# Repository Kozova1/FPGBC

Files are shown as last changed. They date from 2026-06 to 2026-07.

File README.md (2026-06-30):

# FPGBC - Field Programmable Game Boy Cartridge
This is a project for an open-source cartridge for the Game Boy (Color).
Each cartridge contains an iCE40UP5K FPGA, interfacing through level shifters with the Game Boy and through an MCP2210 with your PC.
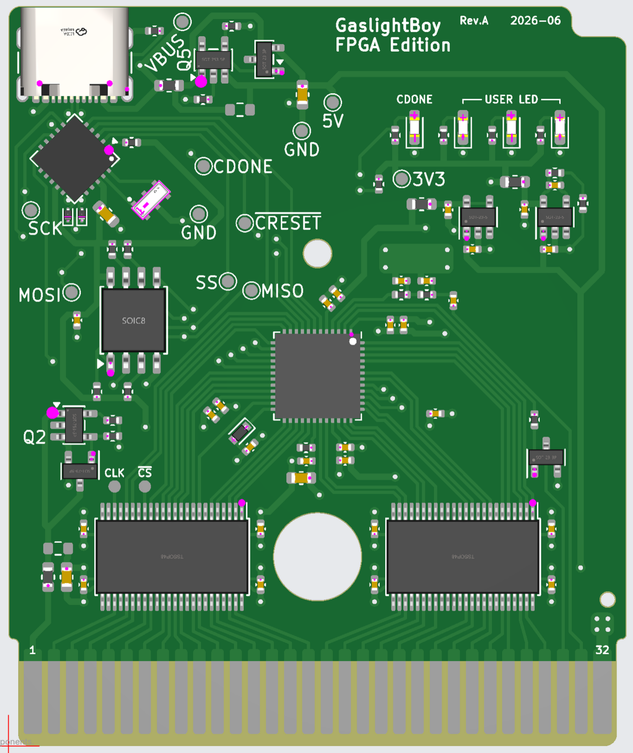
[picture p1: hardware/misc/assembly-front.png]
Field Programmable Game Boy Cartridge


## Licensing
The hardware is licensed under the [BSD 3-clause license](./hardware/LICENSE),
being a modified version of [tsuraraGB](https://github.com/rniwase/tsuraraGB/).

All non-hardware code (including FPGA code, python tooling, etc.) is licensed under the [GPLv3](./LICENSE)

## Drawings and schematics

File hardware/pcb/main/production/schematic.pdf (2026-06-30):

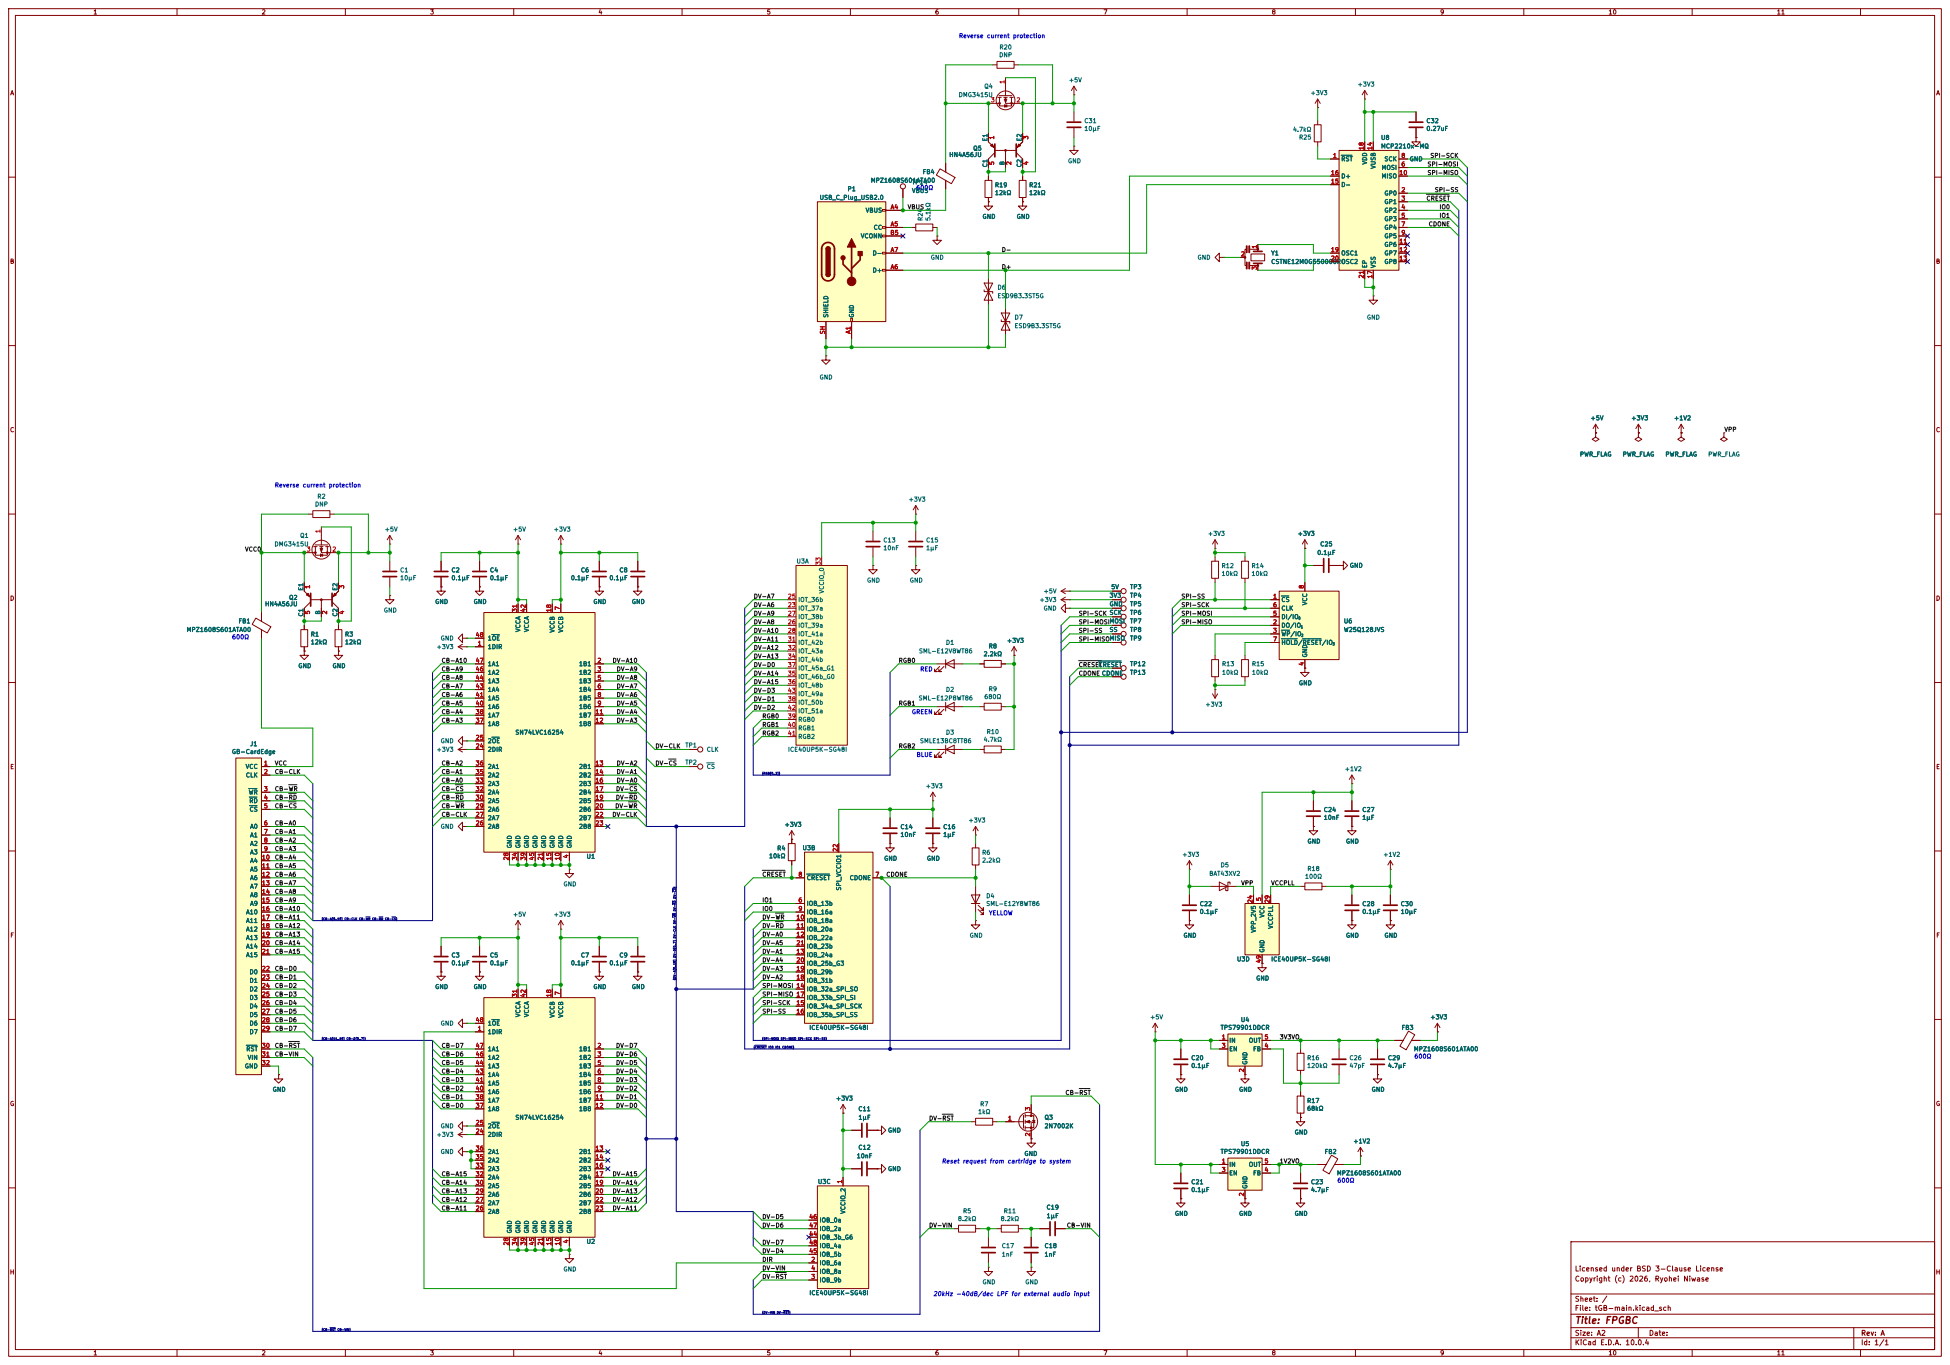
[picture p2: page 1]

GND | D+

BLUE Reverse current protection 600Ω

SPI-SS
SPI-MOSI SPI-SCK

SPI-MOSI SPI-SS CB-RD

{CB-A[0..10] CB-CLK CB-WR CB-RD CB-CS} CB-A12 CB-A10 CB-RST CB-VIN

{SPI-MOSI SPI-MISO SPI-SCK SPI-SS} DV-A0

Reset request from cartridge to system

{DV-VIN DV-RST} DV-VIN

Licensed under BSD 3-Clause License
Copyright (c) 2026, Ryohei Niwase

20kHz -40dB/dec LPF for external audio input

Size: A2 | Rev: A
KiCad E.D.A. 10.0.4 | Id: 1/1

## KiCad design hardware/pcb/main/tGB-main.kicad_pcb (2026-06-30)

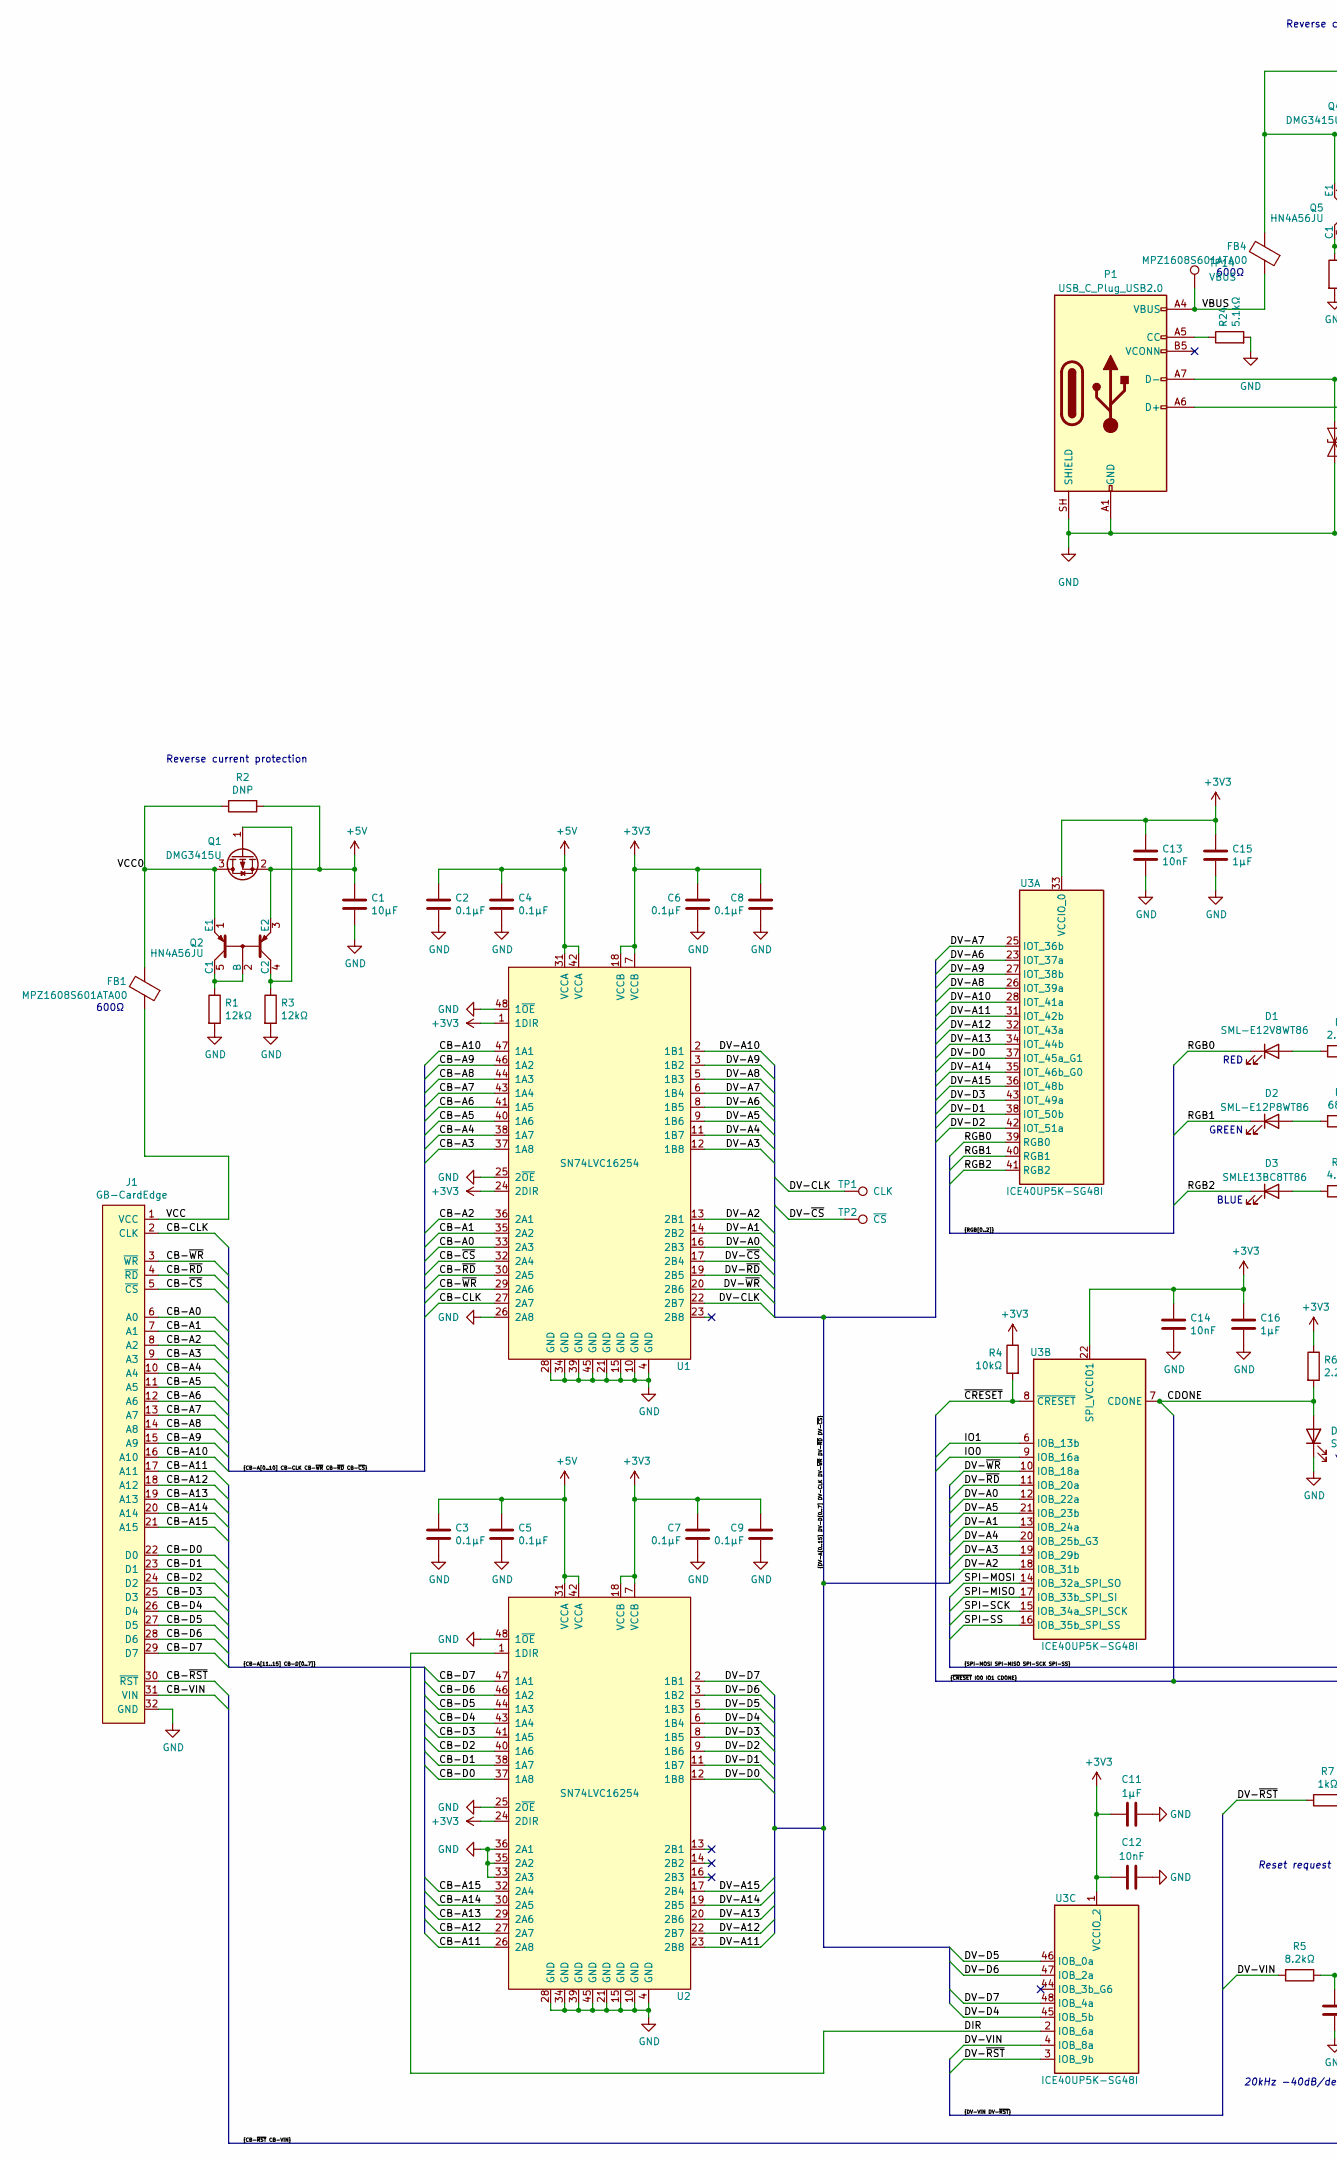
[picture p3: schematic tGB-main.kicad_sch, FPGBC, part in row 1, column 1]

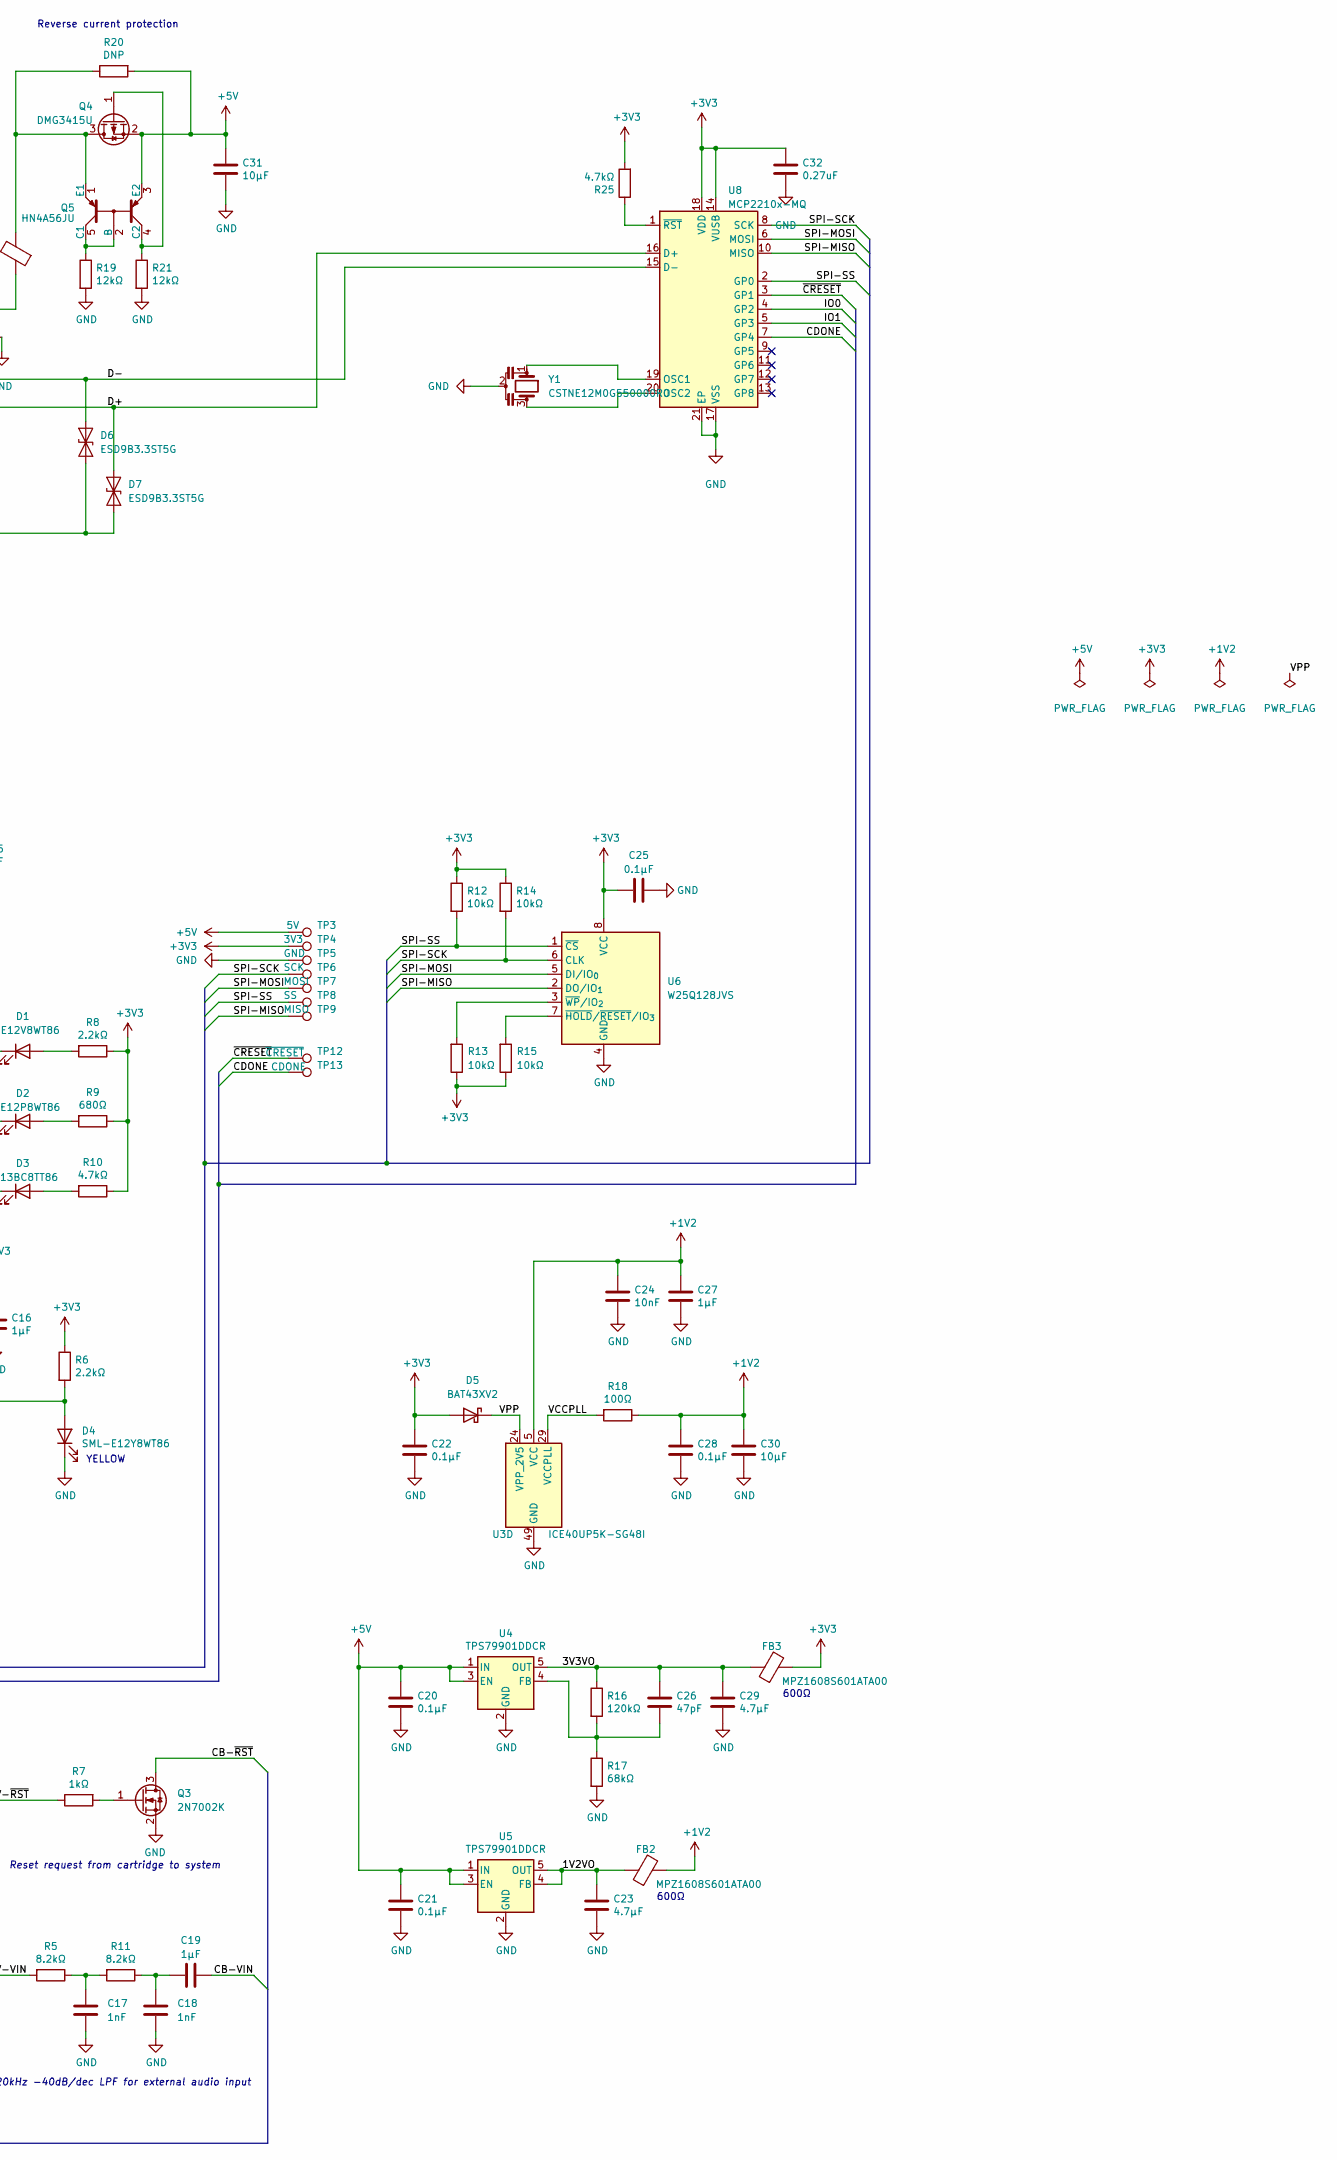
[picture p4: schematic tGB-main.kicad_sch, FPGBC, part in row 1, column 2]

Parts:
C1, C30, C31: 10μF; C_0603_1608Metric
C2, C3, C4, C5, C6, C7, C8, C9, C20, C21, C22, C25, C28: 0.1μF; C_0402_1005Metric
C11, C15, C16, C19, C27: 1μF; C_0402_1005Metric
C12, C13, C14, C24: 10nF; C_0402_1005Metric
C17, C18: 1nF; C_0402_1005Metric
C23, C29: 4.7μF; C_0402_1005Metric
C26: 47pF; C_0402_1005Metric
C32: 0.27uF; C_0603_1608Metric
D1: SML-E12V8WT86; LED_0603_1608Metric_Castellated
D2: SML-E12P8WT86; LED_0603_1608Metric_Castellated
D3: SMLE13BC8TT86; LED_0603_1608Metric_Castellated
D4: SML-E12Y8WT86; LED_0603_1608Metric_Castellated
D5: BAT43XV2; D_SOD-523
D6, D7: ESD9B3.3ST5G; D_SOD-923
FB1, FB2, FB3, FB4: MPZ1608S601ATA00; L_0603_1608Metric
J1: GB-CardEdge
P1: USB_C_Plug_USB2.0; USB_C_Receptacle_GCT_USB4105-xx-A_16P_TopMnt_Horizontal
Q1, Q4: DMG3415U; SOT-23
Q2, Q5: HN4A56JU; SC-74A-5_1.55x2.9mm_P0.95mm
Q3: 2N7002K; SOT-23
R1, R3, R19, R21: 12kΩ; R_0402_1005Metric
R2, R20: DNP; R_0603_1608Metric
R4, R12, R13, R14, R15: 10kΩ; R_0402_1005Metric
R5, R11: 8.2kΩ; R_0402_1005Metric
R6, R8: 2.2kΩ; R_0402_1005Metric
R7: 1kΩ; R_0402_1005Metric
R9: 680Ω; R_0402_1005Metric
R10, R25: 4.7kΩ; R_0402_1005Metric
R16: 120kΩ; R_0402_1005Metric
R17: 68kΩ; R_0402_1005Metric
R18: 100Ω; R_0402_1005Metric
R24: 5.1kΩ; R_0402_1005Metric
TP1: CLK; TestPoint_Pad_D1.0mm
TP2: ~{CS}; TestPoint_Pad_D1.0mm
TP3: 5V; TestPoint_Pad_D1.0mm
TP4: 3V3; TestPoint_Pad_D1.0mm
TP5: GND; TestPoint_Pad_D1.0mm
TP6: SCK; TestPoint_Pad_D1.0mm
TP7: MOSI; TestPoint_Pad_D1.0mm
TP8: SS; TestPoint_Pad_D1.0mm
TP9: MISO; TestPoint_Pad_D1.0mm
TP12: ~{CRESET}; TestPoint_Pad_D1.0mm
TP13: CDONE; TestPoint_Pad_D1.0mm
TP14: VBUS; TestPoint_Pad_D1.0mm
U1, U2: SN74LVC16254; TSSOP-48_6.1x12.5mm_P0.5mm
U3: ICE40UP5K-SG48I; QFN-48-1EP_7x7mm_P0.5mm_EP5.6x5.6mm
U4, U5: TPS79901DDCR; SOT-23-5
U6: W25Q128JVS; SOIC-8_5.3x5.3mm_P1.27mm
U8: MCP2210x-MQ; QFN-20-1EP_5x5mm_P0.65mm_EP3.35x3.35mm
Y1: CSTNE12M0G550000R0; CSTNE10M0G55A000R0

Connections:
+1V2: C24.1, C27.1, C28.1, C30.1, FB2.2, R18.1, U3.5 (VCC), U3.30 (VCC)
+3V3: C6.1, C7.1, C8.1, C9.1, C11.1, C12.1, C13.1, C14.1, C15.1, C16.1, C22.1, C25.1, C32.1, D5.2 (A), FB3.2, R4.1, R6.1, R8.1, R9.1, R10.1, R12.1, R13.1, R14.1, R15.1, R25.2, TP4.1 (1_1), U1.1 (1DIR), U1.7 (VCCB), U1.18 (VCCB), U1.24 (2DIR), U2.7 (VCCB), U2.18 (VCCB), U2.24 (2DIR), U3.1 (VCCIO_2), U3.22 (SPI_VCCIO1), U3.33 (VCCIO_0), U6.8 (VCC), U8.14 (VUSB), U8.18 (VDD); also elsewhere on the board
+5V: C1.1, C2.1, C3.1, C4.1, C5.1, C20.1, C21.1, C31.1, Q1.2 (S), Q2.3 (E2), Q4.2 (S), Q5.3 (E2), R2.2, R20.2, TP3.1 (1_1), U1.31 (VCCA), U1.42 (VCCA), U2.31 (VCCA), U2.42 (VCCA), U4.1 (IN), U4.3 (EN), U5.1 (IN), U5.3 (EN)
/1V2VO: C23.1, FB2.1, U5.4 (FB), U5.5 (OUT)
/3V3VO: C26.1, C29.1, FB3.1, R16.1, U4.5 (OUT)
/CB-A0: J1.6 (A0), U1.33 (2A3)
/CB-A1: J1.7 (A1), U1.35 (2A2)
/CB-A2: J1.8 (A2), U1.36 (2A1)
/CB-A3: J1.9 (A3), U1.37 (1A8)
/CB-A4: J1.10 (A4), U1.38 (1A7)
/CB-A5: J1.11 (A5), U1.40 (1A6)
/CB-A6: J1.12 (A6), U1.41 (1A5)
/CB-A7: J1.13 (A7), U1.43 (1A4)
/CB-A8: J1.14 (A8), U1.44 (1A3)
/CB-A9: J1.15 (A9), U1.46 (1A2)
/CB-A10: J1.16 (A10), U1.47 (1A1)
/CB-A11: J1.17 (A11), U2.26 (2A8)
/CB-A12: J1.18 (A12), U2.27 (2A7)
/CB-A13: J1.19 (A13), U2.29 (2A6)
/CB-A14: J1.20 (A14), U2.30 (2A5)
/CB-A15: J1.21 (A15), U2.32 (2A4)
/CB-CLK: J1.2 (CLK), U1.27 (2A7)
/CB-D0: J1.22 (D0), U2.37 (1A8)
/CB-D1: J1.23 (D1), U2.38 (1A7)
/CB-D2: J1.24 (D2), U2.40 (1A6)
/CB-D3: J1.25 (D3), U2.41 (1A5)
/CB-D4: J1.26 (D4), U2.43 (1A4)
/CB-D5: J1.27 (D5), U2.44 (1A3)
/CB-D6: J1.28 (D6), U2.46 (1A2)
/CB-D7: J1.29 (D7), U2.47 (1A1)
/CB-VIN: C19.1, J1.31 (VIN)
/CB-~CS: J1.5 (~CS), U1.32 (2A4)
/CB-~RD: J1.4 (~RD), U1.30 (2A5)
/CB-~RST: J1.30 (~RST), Q3.3 (D)
/CB-~WR: J1.3 (~WR), U1.29 (2A6)
/CDONE: D4.2 (A), R6.2, TP13.1 (1_1), U3.7 (CDONE), U8.7 (GP4)
/D+: D7.2 (A2), P1.A6 (D+), U8.16 (D+)
/D-: D6.2 (A2), P1.A7 (D-), U8.15 (D-)
/DIR: U2.1 (1DIR), U3.2 (IOB_6a)
/DV-A0: U1.16 (2B3), U3.12 (IOB_22a)
/DV-A1: U1.14 (2B2), U3.13 (IOB_24a)
/DV-A2: U1.13 (2B1), U3.18 (IOB_31b)
/DV-A3: U1.12 (1B8), U3.19 (IOB_29b)
/DV-A4: U1.11 (1B7), U3.20 (IOB_25b_G3)
/DV-A5: U1.9 (1B6), U3.21 (IOB_23b)
/DV-A6: U1.8 (1B5), U3.23 (IOT_37a)
/DV-A7: U1.6 (1B4), U3.25 (IOT_36b)
/DV-A8: U1.5 (1B3), U3.26 (IOT_39a)
/DV-A9: U1.3 (1B2), U3.27 (IOT_38b)
/DV-A10: U1.2 (1B1), U3.28 (IOT_41a)
/DV-A11: U2.23 (2B8), U3.31 (IOT_42b)
/DV-A12: U2.22 (2B7), U3.32 (IOT_43a)
/DV-A13: U2.20 (2B6), U3.34 (IOT_44b)
/DV-A14: U2.19 (2B5), U3.35 (IOT_46b_G0)
/DV-A15: U2.17 (2B4), U3.36 (IOT_48b)
/DV-CLK: TP1.1 (1_1), U1.22 (2B7)
/DV-D0: U2.12 (1B8), U3.37 (IOT_45a_G1)
/DV-D1: U2.11 (1B7), U3.38 (IOT_50b)
/DV-D2: U2.9 (1B6), U3.42 (IOT_51a)
/DV-D3: U2.8 (1B5), U3.43 (IOT_49a)
/DV-D4: U2.6 (1B4), U3.45 (IOB_5b)
/DV-D5: U2.5 (1B3), U3.46 (IOB_0a)
/DV-D6: U2.3 (1B2), U3.47 (IOB_2a)
/DV-D7: U2.2 (1B1), U3.48 (IOB_4a)
/DV-VIN: R5.2, U3.4 (IOB_8a)
/DV-~CS: TP2.1 (1_1), U1.17 (2B4)
/DV-~RD: U1.19 (2B5), U3.11 (IOB_20a)
/DV-~RST: R7.1, U3.3 (IOB_9b)
/DV-~WR: U1.20 (2B6), U3.10 (IOB_18a)
/IO0: U3.9 (IOB_16a), U8.4 (GP2)
/IO1: U3.6 (IOB_13b), U8.5 (GP3)
/RGB0: D1.1 (K), U3.39 (RGB0)
/RGB1: D2.1 (K), U3.40 (RGB1)
/RGB2: D3.1 (K), U3.41 (RGB2)
/SPI-MISO: TP9.1 (1_1), U3.17 (IOB_33b_SPI_SI), U6.2 (DO/IO_{1}), U8.10 (MISO)
/SPI-MOSI: TP7.1 (1_1), U3.14 (IOB_32a_SPI_SO), U6.5 (DI/IO_{0}), U8.6 (MOSI)
/SPI-SCK: R14.2, TP6.1 (1_1), U3.15 (IOB_34a_SPI_SCK), U6.6 (CLK), U8.8 (SCK)
/SPI-SS: R12.2, TP8.1 (1_1), U3.16 (IOB_35b_SPI_SS), U6.1 (~CS), U8.2 (GP0)
/VBUS: FB4.1, P1.A4 (VBUS), P1.A9 (VBUS), P1.B4 (VBUS), P1.B9 (VBUS), TP14.1 (1_1)
/VCC: FB1.1, J1.1 (VCC)
/VCC0: FB1.2, Q1.3 (D), Q2.1 (E1), R2.1
/VCCPLL: R18.2, U3.29 (VCCPLL)
/VPP: D5.1 (K), U3.24 (VPP_2V5)
/~CRESET: R4.2, TP12.1 (1_1), U3.8 (~CRESET), U8.3 (GP1)
GND: C1.2, C2.2, C3.2, C4.2, C5.2, C6.2, C7.2, C8.2, C9.2, C11.2, C12.2, C13.2, C14.2, C15.2, C16.2, C17.2, C18.2, C20.2, C21.2, C22.2, C23.2, C24.2, C25.2, C27.2, C28.2, C29.2, C30.2, C31.2, C32.2, D4.1 (K), D6.1 (A1), D7.1 (A1), J1.32 (GND), P1.A1 (GND), P1.A12 (GND), P1.B1 (GND), P1.B12 (GND), P1.SH (SHIELD), Q3.2 (S), R1.2, R3.2, R17.2, R19.2, R21.2, R24.2, TP5.1 (1_1), U1.4 (GND), U1.10 (GND), U1.15 (GND), U1.21 (GND), U1.25 (2~OE), U1.26 (2A8), U1.28 (GND), U1.34 (GND), U1.39 (GND), U1.45 (GND), U1.48 (1~OE), U2.4 (GND), U2.10 (GND), U2.15 (GND), U2.21 (GND), U2.25 (2~OE), U2.28 (GND), U2.33 (2A3), U2.34 (GND), U2.35 (2A2), U2.36 (2A1), U2.39 (GND), U2.45 (GND), U2.48 (1~OE), U3.49 (GND), U4.2 (GND), U5.2 (GND), U6.4 (GND), U8.17 (VSS), U8.21 (EP), Y1.2; also elsewhere on the board
unnamed: C17.1, R5.1, R11.2
unnamed: C18.1, C19.2, R11.1
unnamed: D1.2 (A), R8.2
unnamed: D2.2 (A), R9.2
unnamed: D3.2 (A), R10.2
unnamed: P1.A5 (CC), R24.1
unnamed: Q1.1 (G), Q2.4 (C2), R3.1
unnamed: Q2.2 (B), Q2.5 (C1), R1.1
unnamed: Q3.1 (G), R7.2
unnamed: FB4.2, Q4.3 (D), Q5.1 (E1), R20.1
unnamed: Q4.1 (G), Q5.4 (C2), R21.1
unnamed: Q5.2 (B), Q5.5 (C1), R19.1
unnamed: C26.2, R16.2, R17.1, U4.4 (FB)
unnamed: R15.2, U6.7 (~HOLD/~RESET/IO_{3})
unnamed: R13.2, U6.3 (~WP/IO_{2})
unnamed: U8.19 (OSC1), Y1.1
unnamed: U8.20 (OSC2), Y1.3
unnamed: R25.1, U8.1 (~RST)

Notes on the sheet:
Reverse current protection
GREEN
600Ω
YELLOW
RED
Reset request from cartridge to system
BLUE
20kHz -40dB/dec LPF for external audio input

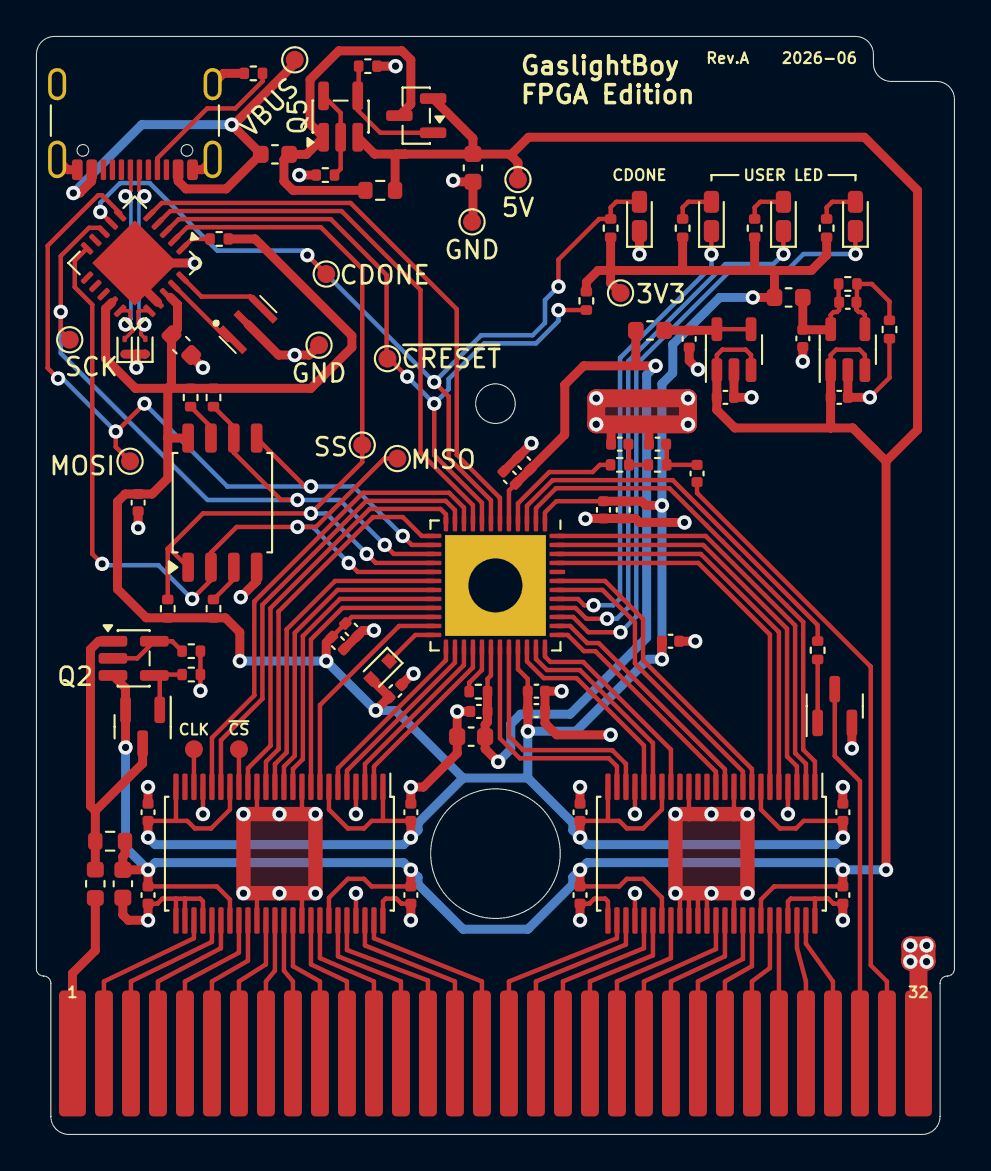
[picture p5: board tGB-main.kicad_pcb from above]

Board: 2 copper layers, 51.0 x 61.0 mm, 94 parts (0 on the bottom side), 103 nets.

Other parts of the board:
C10: 0.1μF; C_0402_1005Metric
TP10: GND; TestPoint_Pad_D1.0mm

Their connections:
+3V3: C10.1; also elsewhere on the board
GND: C10.2, TP10.1 (1_1); also elsewhere on the board

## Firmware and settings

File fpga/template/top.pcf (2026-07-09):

set_io DATA[7] 48
set_frequency DATA[7] 4

set_io DATA[6] 47
set_frequency DATA[6] 4

set_io DATA[5] 46
set_frequency DATA[5] 4

set_io DATA[4] 45
set_frequency DATA[4] 4

set_io DATA[3] 43
set_frequency DATA[3] 4

set_io DATA[2] 42
set_frequency DATA[2] 4

set_io DATA[1] 38
set_frequency DATA[1] 4

set_io DATA[0] 37
set_frequency DATA[0] 4

set_io ADDRESS[15] 36
set_frequency ADDRESS[15] 4

set_io ADDRESS[14] 35
set_frequency ADDRESS[14] 4

set_io ADDRESS[13] 34
set_frequency ADDRESS[13] 4

set_io ADDRESS[12] 32
set_frequency ADDRESS[12] 4

set_io ADDRESS[11] 31
set_frequency ADDRESS[11] 4

set_io ADDRESS[10] 28
set_frequency ADDRESS[10] 4

set_io ADDRESS[9] 27
set_frequency ADDRESS[9] 4

set_io ADDRESS[8] 26
set_frequency ADDRESS[8] 4

set_io ADDRESS[7] 25
set_frequency ADDRESS[7] 4

set_io ADDRESS[6] 23
set_frequency ADDRESS[6] 4

set_io ADDRESS[5] 21
set_frequency ADDRESS[5] 4

set_io ADDRESS[4] 20
set_frequency ADDRESS[4] 4

set_io ADDRESS[3] 19
set_frequency ADDRESS[3] 4

set_io ADDRESS[2] 18
set_frequency ADDRESS[2] 4

set_io ADDRESS[1] 13
set_frequency ADDRESS[1] 4

set_io ADDRESS[0] 12
set_frequency ADDRESS[0] 4

set_io nRD 11
set_frequency nRD 4

set_io nWR 10
set_frequency nWR 4

set_io nRST 3
set_frequency nRST 4

set_io VIN 4
set_frequency VIN 4

set_io DIR_DATA 2
set_frequency DIR_DATA 4

set_io SPI_SCK 15
set_frequency SPI_SCK 4

set_io SPI_MOSI 14
set_frequency SPI_MOSI 4

set_io SPI_MISO 17
set_frequency SPI_MISO 4

set_io SPI_SS 16
set_frequency SPI_SS 4

set_io IO[1] 6
set_frequency IO[1] 4

set_io IO[0] 9
set_frequency IO[0] 4

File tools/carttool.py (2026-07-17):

import argparse
from itertools import batched
import math
from pathlib import Path
import time

import hid
import mcp2210

from loguru import logger
from mcp2210.mcp2210 import Mcp2210GpioDirection, Mcp2210GpioDesignation
from tqdm import tqdm, trange

from tools.spi_flash import W25Q128JVS

from .types import hex_integer
from .argparse_tree import Argument, LeafCommand, Command, make_parser

PROGRAM_NAME = "carttool.py"

USB_VID = 0x04D8
USB_PID = 0xE429

MCP2210_IO_CONFIG_COMMAND = bytes.fromhex(
    "60 20 00 00 " # Set Chip NVRAM Power-up Default
    "01 00 00 00 00 00 00 00 00 " # GP0 -> CSn, GP1-8 -> GPIO
    "03 00 " # CSn -> 1, RESETn -> 1, all others -> 0
    "FF 01 " # all -> input
    "00 00 " # No SPI bus release or protection
    "00 00 00 00 00 00 00 00 " # Do not set password
)

MCP2210_USB_ID_CONFIG_COMMAND = bytes.fromhex(
    "60 30 00 00 " # Set Chip NVRAM USB Power-up parameters
    f"{USB_VID & 0xFF:02X} {(USB_VID >> 8) & 0xFF:02X} " # USB VID
    f"{USB_PID & 0xFF:02X} {(USB_PID >> 8) & 0xFF:02X} " # USB PID
    "40 " # Self-powered (a lie, but the USB power circuitry is separated from the MCP2210)
    f"{250:02X} " # Request max current from the host
)

MANUFACTURER_NAME = "Vogman Devices".encode("UTF-16-LE")
DEVICE_NAME = "FPGBC".encode("UTF-16-LE")

MCP2210_USB_MANUFACTURER_CONFIG_COMMAND = bytes.fromhex(
    "60 50 00 00 " + # Set Chip NVRAM USB Manufacturer name
    f"{len(MANUFACTURER_NAME) * 2 + 2:02X} " + # Length(UTF16LE)*2+2 as per docs
    MANUFACTURER_NAME.hex(" ") + " "
)

MCP2210_USB_NAME_CONFIG_COMMAND = bytes.fromhex(
    "60 40 00 00" + # Set Chip NVRAM USB Product name
    f"{len(DEVICE_NAME) * 2 + 2:02X} " + # Length(UTF16LE)*2+2 as per docs
    DEVICE_NAME.hex(" ") + " "
)

SS_PIN_NUMBER = 0
RESET_PIN_NUMBER = 1
CDONE_PIN_NUMBER = 4

class Cartridge:
    _spi: mcp2210.mcp2210.Mcp2210
    _serial_number: str

    def __init__(self, serial_number: str):
        self._serial_number = serial_number
        self._spi = mcp2210.mcp2210.Mcp2210(
            serial_number=self._serial_number,
            vendor_id=USB_VID,
            product_id=USB_PID
        )

    @staticmethod
    def list_serials(vid: int = USB_VID, pid: int = USB_PID) -> list[str]:
        return [
            dev["serial_number"]
            for dev in hid.enumerate(vendor_id=vid, product_id=pid)
        ]

    def reset_fpga(self):
        self._spi.set_gpio_output_value(RESET_PIN_NUMBER, True)

    def program_flash(self, image: bytes, mass_erase: bool = False, verify_only: bool = False, skip_verify: bool = False):
        logger.info("Configuring MCP2210 GPIO/SPI for programming the flash")
        self._spi.set_spi_mode(3)
        self._spi.set_gpio_designation(SS_PIN_NUMBER, Mcp2210GpioDesignation.CHIP_SELECT)
        self._spi.set_gpio_designation(RESET_PIN_NUMBER, Mcp2210GpioDesignation.GPIO)
        self._spi.set_gpio_direction(RESET_PIN_NUMBER, Mcp2210GpioDirection.OUTPUT)
        logger.info("Resetting the FPGA...")
        self._spi.set_gpio_output_value(RESET_PIN_NUMBER, False)
        time.sleep(1e-3)
        flash = W25Q128JVS(self._spi, SS_PIN_NUMBER)
        flash.wakeup()
        logger.info(f"flash JEDEC ID: {flash.jedec_id}")

        if (len(image) % flash.SECTOR_SIZE) != 0:
            padding_count = len(image) % flash.SECTOR_SIZE
            logger.warning(f"Image not aligned to sector size ({flash.SECTOR_SIZE}). {padding_count} bytes after image will be erased and not programmed (left as FF)")
            image = image + (b"\xFF" * padding_count)

        if not verify_only:
            if mass_erase:
                flash.write_enable()
                flash.chip_erase()
                flash.wait_for_program(True)
            else:
                with tqdm(total=len(image), unit="B", unit_scale=True, unit_divisor=1024, desc="erasing flash") as pbar:
                    for step in flash.erase_range(0, len(image)):
                        pbar.update(step)
                    pbar.colour = "green"

        if not verify_only:
            with tqdm(total=len(image), unit="B", unit_scale=True, unit_divisor=1024, desc="programming flash") as pbar:
                for step in flash.program_range(0, image):
                    pbar.update(step)
                pbar.colour = "green"
        
        verification_success = True
        if not skip_verify:
            with tqdm(total=len(image), unit="B", unit_scale=True, unit_divisor=1024, desc="verifying flash") as pbar:
                for page_base in range(0, len(image), flash.PAGE_SIZE):
                    img = image[page_base:page_base+flash.PAGE_SIZE]
                    fls = flash[page_base:page_base+flash.PAGE_SIZE]
                    if img != fls:
                        logger.warning(f"mismatch at addresses {[
                            hex(page_base + j)
                            for j, (l, r) in enumerate(zip(img, fls))
                            if l != r
                        ]}")
                        pbar.colour = "red"
                        verification_success = False
                    pbar.update(flash.PAGE_SIZE)
            
                if verification_success:
                    pbar.colour = "green"
                    pbar.refresh()
                    logger.success("Finished programming")
                else:
                    logger.warning("Finished programming, flash doesn't match image")



    def program_fpga(self, image: bytes):
        logger.critical("Programming FPGA directly is not implemented using MCP2210")


def list_mcp2210(args: argparse.Namespace):
    devs = list(hid.enumerate(args.vendor_id, args.product_id))
    if not devs:
        logger.warning("No MCP2210 devices found")
        return

    for dev in devs:
        print(dev["serial_number"])

def program_mcp2210(args: argparse.Namespace):
    assert len(MANUFACTURER_NAME) < (63-6)
    assert len(DEVICE_NAME) < (63-6)
    logger.info(f"Connecting to MCP2210 with USB VID:PID:SERIAL = {args.vendor_id}:{args.product_id}:{args.serial_number}")
    mcp = mcp2210.mcp2210.Mcp2210(
        serial_number=args.serial_number,
        vendor_id=args.vendor_id,
        product_id=args.product_id,
    )
    logger.info("Connected to MCP2210")

    logger.info("Programming IO config...")
    response = mcp._execute_command(MCP2210_IO_CONFIG_COMMAND, pad_with_zeros=True, check_return_code=True)
    logger.debug(f"MCP2210 response: {response.hex(' ')}")

    logger.info(f"Programming USB VID:PID..")
    response = mcp._execute_command(MCP2210_USB_ID_CONFIG_COMMAND, pad_with_zeros=True, check_return_code=True)
    logger.debug(f"MCP2210 response: {response.hex(' ')}")

    logger.info(f"Programming USB manufacturer..")
    response = mcp._execute_command(MCP2210_USB_MANUFACTURER_CONFIG_COMMAND, pad_with_zeros=True, check_return_code=True)
    logger.debug(f"MCP2210 response: {response.hex(' ')}")

    logger.info(f"Programming USB device name..")
    response = mcp._execute_command(MCP2210_USB_NAME_CONFIG_COMMAND, pad_with_zeros=True, check_return_code=True)
    logger.debug(f"MCP2210 response: {response.hex(' ')}")

    logger.success(f"MCP2210 programming complete")

def list_carts(args: argparse.Namespace):
    for cart_serial in Cartridge.list_serials(vid=args.vendor_id, pid=args.product_id):
        print(cart_serial)

def program_fpga(args: argparse.Namespace):
    pass

def program_flash(args: argparse.Namespace):
    cart = Cartridge(args.serial_number)
    cart.program_flash(
        args.image.read_bytes(),
        mass_erase=args.mass_erase,
        verify_only=args.verify_only,
        skip_verify=args.skip_verify,
    )
    if args.reset_fpga:
        cart.reset_fpga()


def get_serial_number(args: argparse.Namespace) -> str | None:
    if args.serial_number is not None:
        return args.serial_number

    serials = Cartridge.list_serials(vid=args.vendor_id, pid=args.product_id)
    if not serials:
        logger.error("No serial numbers found")
        return None

    if len(serials) > 1:
        logger.error("Multiple serial numbers found:")
        for serial in serials:
            print(f"  {serial}")
        return None

    return serials[0]


def get_args_decl():
    desc = Command(
        {
            "list": Command(
                {
                    "cart": LeafCommand(
                        list_carts,
                        help="list connected carts",
                    ),
                    "mcp2210": LeafCommand(
                        list_mcp2210,
                        help="list connected MCP2210 devices",
                    )
                },
                help="list connected devices",
            ),
            "program": Command(
                {
                    "mcp2210": LeafCommand(
                        program_mcp2210,
                        help="program connected MCP2210 device with cartridge default settings",
                    ),
                    "fpga": LeafCommand(
                        program_fpga,
                        help="program cartridge FPGA ephemerally",
                    ),
                    "flash": LeafCommand(
                        program_flash,
                        help="program cartridge flash memory",
                        arguments=[
                            Argument("--image", required=True, type=Path, help="path to SPI flash image", dest="image"),
                            Argument("--mass-erase", action="store_true", help="use mass erase instead of localized erase", dest="mass_erase"),
                            Argument("--verify-only", action="store_true", help="only verify the flash instead of programming it", dest="verify_only"),
                            Argument("--do-not-verify", action="store_true", help="do not verify flash writes (dangerous!)", dest="skip_verify"),
                            Argument("--reset-fpga", action="store_true", help="reset the FPGA after flashing", dest="reset_fpga"),
                        ]
                    ),
                },
                help="program connected devices",
            ),
        },
        [
            Argument("--serial-number", dest="serial_number", default=None, help="the serial number of the MCP2210 (optional if only one is connected)"),
            Argument("--vendor-id", type=hex_integer, help=f"USB vendor ID in hex (0x{USB_VID:04X} by default)", default=USB_VID, dest="vendor_id"),
            Argument("--product-id", type=hex_integer, help=f"USB product ID in hex (0x{USB_PID:04x} by default)", default=USB_PID, dest="product_id"),
        ],
    )

    parser = make_parser(PROGRAM_NAME, desc)

    args = parser.parse_args()
    args.serial_number = get_serial_number(args)
    return args


def main():
    args = get_args_decl()

    if args.serial_number is not None:
        args.main_func(args)


if __name__ == "__main__":
    main()

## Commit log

2026-06-30 Add source files
    [tGB-main.kicad_pcb, tGB-main.kicad_sch]
2026-07-06 Fix argument handling and imports
    [argparse_tree.py, carttool.py]
